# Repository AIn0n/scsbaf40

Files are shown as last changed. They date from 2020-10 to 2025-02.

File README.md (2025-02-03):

# SCSBAF40
 

Staggered Columns Split Budget AF 40% ergonomic keyboard
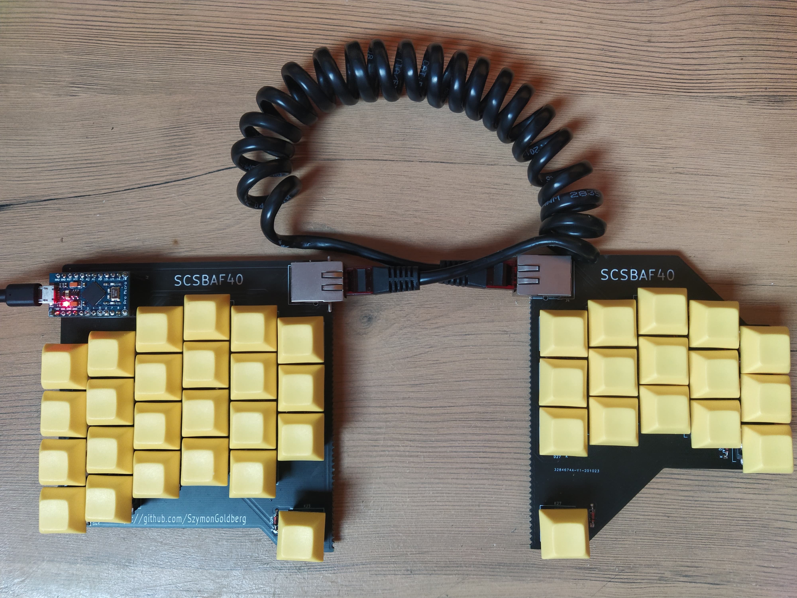
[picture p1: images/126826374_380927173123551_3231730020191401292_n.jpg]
SCSBAF40


The SCSBAF40 keyboard is 40% Staggered Columns Split Budget AF ergonomic keyboard.
Heavly inspired by [REVIUNG34](https://github.com/gtips/reviung) and [Squiggle](https://github.com/ibnuda/Squiggle).

[typing demo](https://www.youtube.com/watch?v=xkb4R93yoao)

## Overview

Project goals:
- single arduino, simple design
- split
- staggered columns with dimensions fitting my fingers length
- easy to build with easily obtainable and cheap parts
- all software written in arduino IDE
- minimum 40 keys (that's main difference between this project and squiggle or reviung)

## Parts list

| Qnty | Parts | price (per piece) |
| --- | --- | --- |
| 1 | PCB | ~5$ |
| 1 | pro micro | ~3$ |
| 2 | Ethernet connector | ~1$ |
| 8 | rubber feet | <1$ |
| 40 | 1N4148 DO-35 diode | <1$ |
| 40 | MX compatible keycap (1U) | <1$ |
| 40 | MX compatible switch | 0.2$ (gateron) |

## Default layout
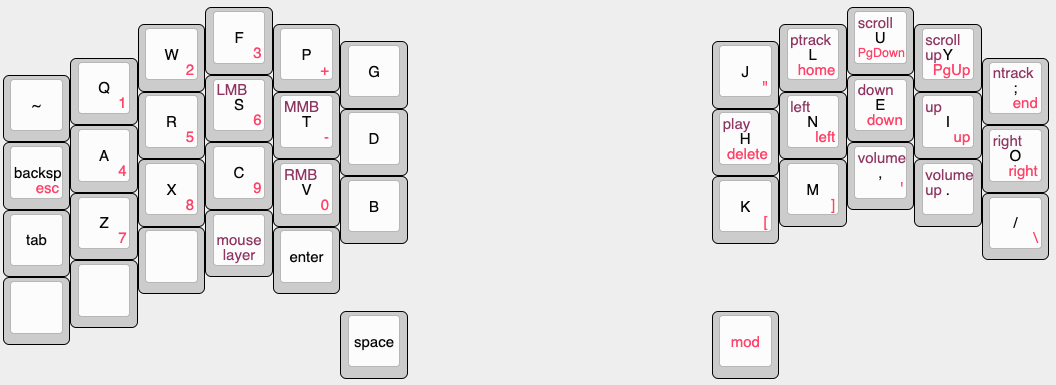
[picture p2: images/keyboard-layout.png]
layout


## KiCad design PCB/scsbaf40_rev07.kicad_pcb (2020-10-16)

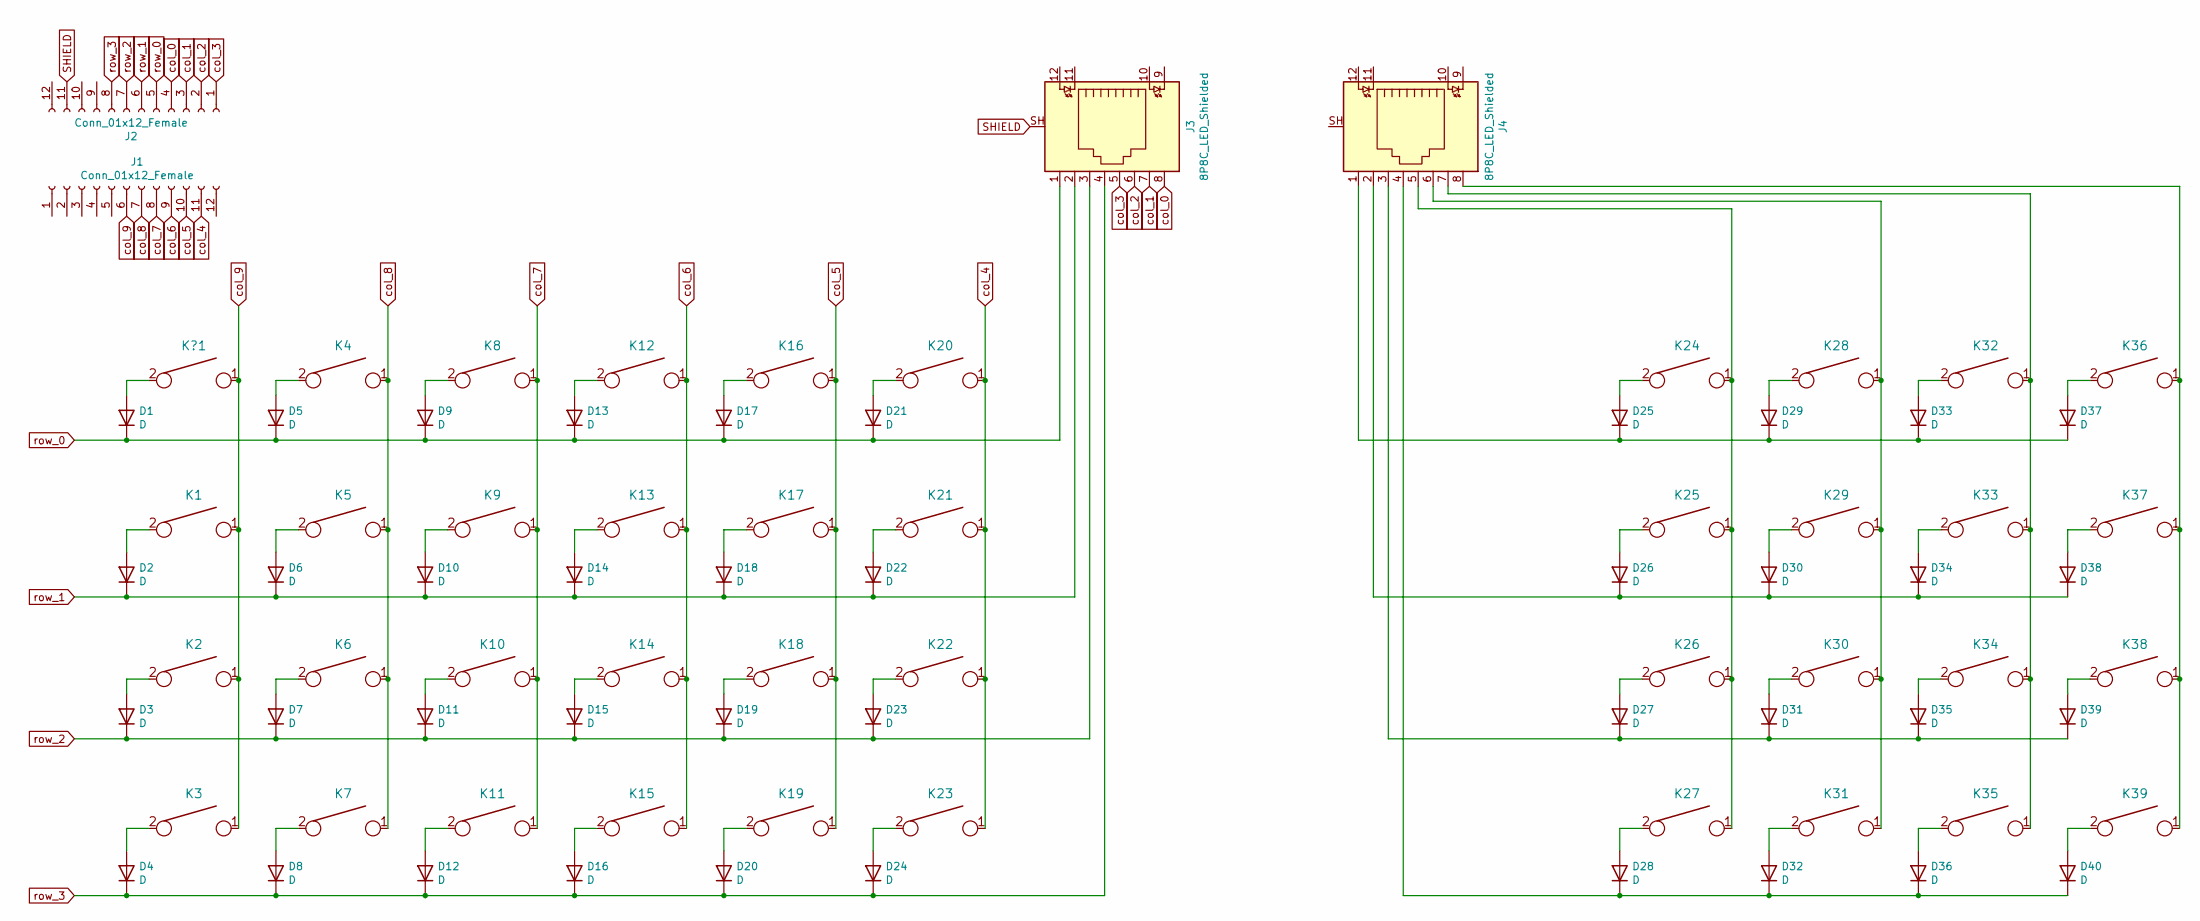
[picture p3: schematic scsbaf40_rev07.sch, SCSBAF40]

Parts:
D1, D2, D3, D4, D5, D6, D7, D8, D9, D10, D11, D12, D13, D14, D15, D16, D17, D18, D19, D20, D21, D22, D23, D24, D25, D26, D27, D28, D29, D30, D31, D32, D33, D34, D35, D36, D37, D38, D39, D40: D; D_DO-35_SOD27_P7.62mm_Horizontal
J1, J2: Conn_01x12_Female; PinSocket_1x12_P2.54mm_Vertical
J3, J4: 8P8C_LED_Shielded; RJ45_Wuerth_7499010001A_Horizontal
K1, K2, K3, K4, K5, K6, K7, K8, K9, K10, K11, K12, K13, K14, K15, K16, K17, K18, K19, K20, K21, K22, K23, K24, K25, K26, K27, K28, K29, K30, K31, K32, K33, K34, K35, K36, K37, K38, K39: KEYSW; SW_Cherry_MX_1.00u_PCB
K?1: KEYSW; SW_Cherry_MX_1.00u_PCB

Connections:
unnamed: D1.2 (A), K?1.2
unnamed: D2.2 (A), K1.2
unnamed: D3.2 (A), K2.2
unnamed: D4.2 (A), K3.2
unnamed: D5.2 (A), K4.2
unnamed: D6.2 (A), K5.2
unnamed: D7.2 (A), K6.2
unnamed: D8.2 (A), K7.2
unnamed: D9.2 (A), K8.2
unnamed: D10.2 (A), K9.2
unnamed: D11.2 (A), K10.2
unnamed: D12.2 (A), K11.2
unnamed: D13.2 (A), K12.2
unnamed: D14.2 (A), K13.2
unnamed: D15.2 (A), K14.2
unnamed: D16.2 (A), K15.2
unnamed: D17.2 (A), K16.2
unnamed: D18.2 (A), K17.2
unnamed: D19.2 (A), K18.2
unnamed: D20.2 (A), K19.2
unnamed: D21.2 (A), K20.2
unnamed: D22.2 (A), K21.2
unnamed: D23.2 (A), K22.2
unnamed: D24.2 (A), K23.2
unnamed: D25.1 (K), D29.1 (K), D33.1 (K), D37.1 (K), J4.1
unnamed: D25.2 (A), K24.2
unnamed: D26.1 (K), D30.1 (K), D34.1 (K), D38.1 (K), J4.2
unnamed: D26.2 (A), K25.2
unnamed: D27.1 (K), D31.1 (K), D35.1 (K), D39.1 (K), J4.3
unnamed: D27.2 (A), K26.2
unnamed: D28.1 (K), D32.1 (K), D36.1 (K), D40.1 (K), J4.4
unnamed: D28.2 (A), K27.2
unnamed: D29.2 (A), K28.2
unnamed: D30.2 (A), K29.2
unnamed: D31.2 (A), K30.2
unnamed: D32.2 (A), K31.2
unnamed: D33.2 (A), K32.2
unnamed: D34.2 (A), K33.2
unnamed: D35.2 (A), K34.2
unnamed: D36.2 (A), K35.2
unnamed: D37.2 (A), K36.2
unnamed: D38.2 (A), K37.2
unnamed: D39.2 (A), K38.2
unnamed: D40.2 (A), K39.2
unnamed: J4.5, K24.1, K25.1, K26.1, K27.1
unnamed: J4.6, K28.1, K29.1, K30.1, K31.1
unnamed: J4.7, K32.1, K33.1, K34.1, K35.1
unnamed: J4.8, K36.1, K37.1, K38.1, K39.1
SHIELD: J2.11, J3.SH
col_0: J2.4, J3.8
col_1: J2.3, J3.7
col_2: J2.2, J3.6
col_3: J2.1, J3.5
col_4: J1.11, K20.1, K21.1, K22.1, K23.1
col_5: J1.10, K16.1, K17.1, K18.1, K19.1
col_6: J1.9, K12.1, K13.1, K14.1, K15.1
col_7: J1.8, K8.1, K9.1, K10.1, K11.1
col_8: J1.7, K4.1, K5.1, K6.1, K7.1
col_9: J1.6, K1.1, K2.1, K3.1, K?1.1
row_0: D1.1 (K), D5.1 (K), D9.1 (K), D13.1 (K), D17.1 (K), D21.1 (K), J2.5, J3.1
row_1: D2.1 (K), D6.1 (K), D10.1 (K), D14.1 (K), D18.1 (K), D22.1 (K), J2.6, J3.2
row_2: D3.1 (K), D7.1 (K), D11.1 (K), D15.1 (K), D19.1 (K), D23.1 (K), J2.7, J3.3
row_3: D4.1 (K), D8.1 (K), D12.1 (K), D16.1 (K), D20.1 (K), D24.1 (K), J2.8, J3.4

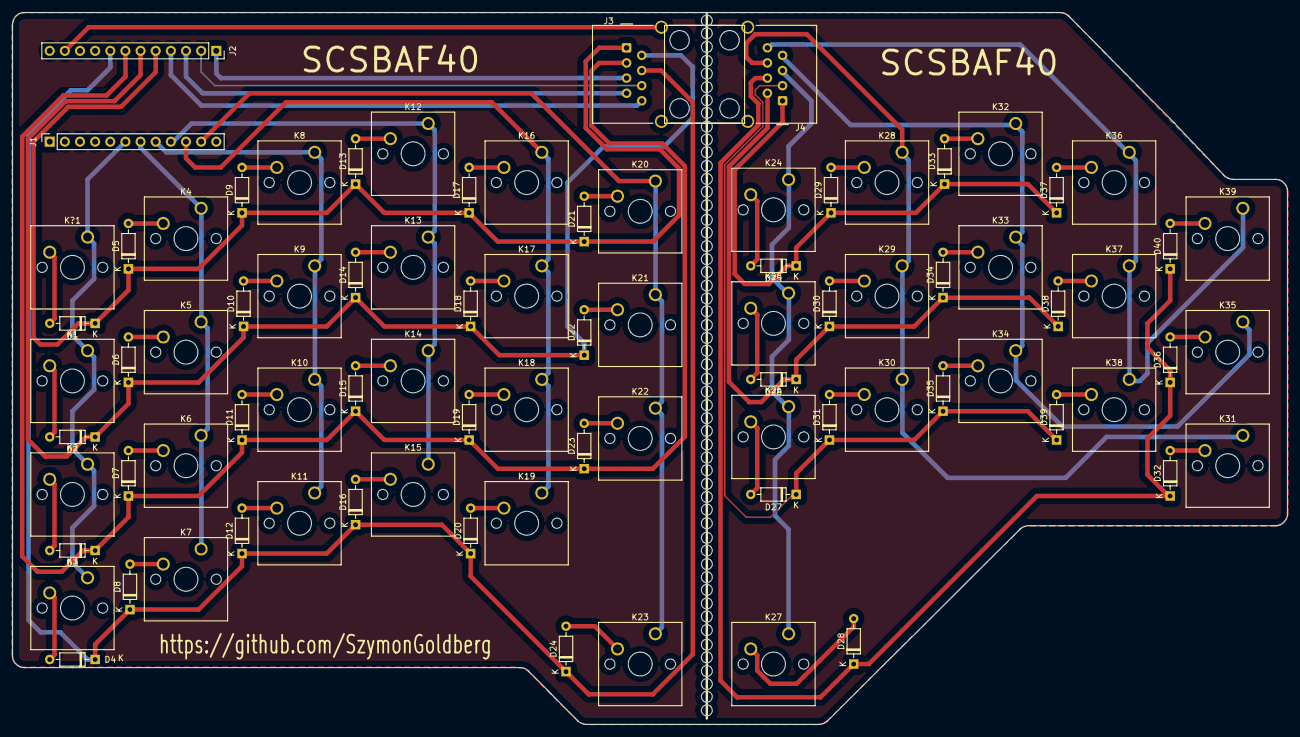
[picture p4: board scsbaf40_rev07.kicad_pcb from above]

Board: 2 copper layers, 213.9 x 119.4 mm, 84 parts (0 on the bottom side), 63 nets.

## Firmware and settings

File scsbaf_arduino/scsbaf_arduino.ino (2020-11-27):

#include <Keyboard.h> //library for send signal to PC via USB

#define COLS_SIZE 10  //number of columns
#define ROWS_SIZE 4   //number of rows
#define MIN_MS 20     //minimum time in ms after which button can be active again
#define REPEAT_MS 600 //minimum time in ms after which button is automticly re-active
#define RELAY_TIME 1  //time duration of key press

//https://www.arduino.cc/reference/en/language/functions/usb/keyboard/keyboardmodifiers/
#define K_CTRL  (uint8_t)128
#define K_SHFT  (uint8_t)129
#define K_ALT   (uint8_t)130
#define K_SUPR  (uint8_t)131
#define K_BACK  (uint8_t)178
#define K_RET   (uint8_t)176
#define K_ESC   (uint8_t)177
#define K_TAB   (uint8_t)179
#define K_DEL   (uint8_t)212

//arrows
#define K_UP    (uint8_t)218
#define K_DN    (uint8_t)217
#define K_LF    (uint8_t)216
#define K_RG    (uint8_t)215

//page up/down
#define K_PGUP  (uint8_t)211
#define K_PGDN  (uint8_t)214

//home/end
#define K_HOME  (uint8_t)210
#define K_END   (uint8_t)213

//mod key
#define K_MOD1 (uint8_t)1

const byte COLS[] = {3, 4, 5, 6, 7, 8, 10, 16, 14, 15};   //columns pins
const byte ROWS[] = {A0, A1, A2, A3};                     //rows pins

//keyboard layout - first one is default, next one is applied when K_MOD1 is pressed
uint8_t key_matrix[2][40] = {
{ K_TAB,  'q',    'w',    'f',    'p',    'g',    'j',    'l',    'u',    'y',
  K_BACK, 'a',    'r',    's',    't',    'd',    'h',    'n',    'e',    'i',
  K_SHFT, 'z',    'x',    'c',    'v',    'b',    'k',    'm',    ',',    '.', 
  K_CTRL, K_SUPR, K_ALT,  '[',    ']',    ' ',    K_MOD1,                            '/',    'o',    ';'},
                          
{ '`',    '1',    '2',    '3',    '=',    'g',    '\'',   K_HOME,  K_PGDN,  K_PGUP,
  K_ESC,  '4',    '5',    '6',    '-',    'd',    K_DEL,  K_LF,    K_DN,    K_UP,
  K_SHFT, '7',    '8',    '9',    '0',    'b',    'k',    'm',     ',',     '.', 
  K_CTRL, K_SUPR, K_ALT,  '[',    ']',    K_RET,  K_MOD1,                            '\\',    K_RG,    K_END},

};

typedef enum {DFLT = 0, HOLD = 1, MCRO = 2}__attribute__((packed)) key_type;

//type of key
//DFLT - (default) normal keys
//HOLD - special, often hold down keys like control, shift, etc
//MCRO - macro keys (they change layout if pressed)

key_type type_matrix[2][40] = {
{ HOLD,    DFLT,      DFLT,        DFLT,      DFLT,      DFLT,       DFLT,      DFLT,      DFLT,       DFLT,
  DFLT,    DFLT,      DFLT,        DFLT,      DFLT,      DFLT,       DFLT,      DFLT,      DFLT,       DFLT,
  HOLD,    DFLT,      DFLT,        DFLT,      DFLT,      DFLT,       DFLT,      DFLT,      DFLT,       DFLT,
  HOLD,    HOLD,      HOLD,        DFLT,      DFLT,      DFLT,       MCRO,                             DFLT,      DFLT,       DFLT},

{ HOLD,    DFLT,      DFLT,        DFLT,      DFLT,      DFLT,       DFLT,      DFLT,      DFLT,       DFLT,
  DFLT,    DFLT,      DFLT,        DFLT,      DFLT,      DFLT,       DFLT,      DFLT,      DFLT,       DFLT,
  HOLD,    DFLT,      DFLT,        DFLT,      DFLT,      DFLT,       DFLT,      DFLT,      DFLT,       DFLT,
  HOLD,    HOLD,      HOLD,        DFLT,      DFLT,      DFLT,       MCRO,                             DFLT,      DFLT,       DFLT}
};

typedef enum {INACTIVE = 0, ACTIVE = 1, LONG_ACTIVE = 2}__attribute__((packed)) key_state;

key_state state[40] = {INACTIVE};            //0 - inactive, 1 - pushed, 2 - long_active (if button is pressed down for longer than REPEAT_MS)
unsigned long saturation[40] = {0}; //time at the moment when the button is pressed

uint8_t pressed;                    //state flag in key_data_upate function
uint8_t modifier = 0;               //flag which point to current layout

void key_data_update(uint8_t idx, uint8_t V_state)
{
  pressed = 0;
  if(V_state == LOW)
  {
    if (millis() - saturation[idx] > MIN_MS)
    {
      if(state[idx] == 0)
      {
        state[idx] = ACTIVE;
        pressed = 1;
      }
      else if (state[idx] == 1 && (millis() - saturation[idx] > REPEAT_MS))
      {
          state[idx] = LONG_ACTIVE;
          pressed = 1;
      }
      else if (state[idx]== LONG_ACTIVE){pressed = 1;}
    }
  }
  else
  {
    if(type_matrix[modifier][idx] == HOLD && state[idx]) Keyboard.release(key_matrix[modifier][idx]);
    if(type_matrix[modifier][idx] == MCRO && state[idx]) modifier = 0;
    state[idx] = INACTIVE;
    saturation[idx] = 0;
  }
  
  if(pressed)
  {
    saturation[idx] = millis();
    if(type_matrix[modifier][idx] == DFLT)
    {
      Keyboard.press(key_matrix[modifier][idx]);
      delay(RELAY_TIME);
      Keyboard.release(key_matrix[modifier][idx]);
    }
    if(type_matrix[modifier][idx] == HOLD) { Keyboard.press(key_matrix[modifier][idx]); }
    if(type_matrix[modifier][idx] == MCRO) {modifier = key_matrix[modifier][idx];}
  }
}

void setup() {
  Keyboard.begin();
  for (int i = 0; i < COLS_SIZE; ++i) pinMode(COLS[i], INPUT_PULLUP);
  for (int i = 0; i < ROWS_SIZE; ++i) pinMode(ROWS[i], OUTPUT);
}

void loop()
{
  //all delays in loops are required to stabilize voltage in circuit
  for (int i = 0; i < ROWS_SIZE; ++i)
  {
    digitalWrite(ROWS[i], LOW);
    delay(1);
    for (int g = 0; g < COLS_SIZE; ++g)
    {
      pinMode(COLS[g], INPUT_PULLUP);
      key_data_update(g + COLS_SIZE * i, digitalRead(COLS[g]));
      digitalWrite(COLS[i], HIGH);
      delay(1);
    }
    digitalWrite(ROWS[i], HIGH);
    delay(1);
  }
}

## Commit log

2020-10-13 Added kiCAD files.
    [scsbaf40.kicad_pcb, scsbaf40.sch, scsbaf40_right.kicad_pcb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]
2020-10-16 Some minor changes on PCB project
    [scsbaf40.kicad_pcb, scsbaf40.sch, scsbaf40_rev07.kicad_pcb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]
2020-11-21 Added code for pro micro
    [scsbaf40_rev07.kicad_pcb, scsbaf40_rev07.sch]
2020-11-21 Removed duplicated folder
    [scsbaf40_rev07.kicad_pcb, scsbaf40_rev07.sch]
